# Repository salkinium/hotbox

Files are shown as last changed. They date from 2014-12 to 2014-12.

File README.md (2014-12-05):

# HotBox

HotBox, a solution with the following properties:

1. It allows exposition of sensor motes to a wide range of temper- atures with a high degree of accuracy.
2. It supports specifying exact spatial orientation of motes which, if not ensured, interferes with repeatable experiment setups. 
3. It is reasonably easy to assemble by following the information (code, PCB schematics, hardware list and crafting instructions) available online, facilitating further use of the platforms by other researchers.

For further information have a look at the [HotBox technical report][hotbox].

## Organization

This repository is organized as follows:

- 	The *hardware* folder contains all hardware files for the box.
	-	*hardware/et* contains the PCB schematics and layouts.
	-	*hardware/baseboard* contains the vector files of all parts of the baseboard (for the lasercutter).
	-	*hardware/harness* contains the vector files of all parts of the mote harness (for the lasercutter).
- 	The *software* folder contains the software for the controller.
	- 	*software/source* contains the actual application code for this robot.
	-	*software/xpcc* contains the git submodule for the xpcc.io microcontroller framework.

All hardware and embedded software was designed by [Niklas Hauser][hauser] during his [bachelor thesis][bachelor].

[hotbox]: http://sunsite.informatik.rwth-aachen.de/Publications/AIB/2014/2014-14.pdf
[hauser]: http://www.salkinium.de
[bachelor]: https://github.com/salkinium/bachelor

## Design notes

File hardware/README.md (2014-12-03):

# Box Controller Hardware

## Controller PCB

The controller is build around a ATmega328p on a PCB which contains:

- a UART PSK plug for communication,
- a reset button,
- 4 PSK plugs for I2C bus with pull-ups,
- a ISP programming header,
- 4 mounting holes,
- a ATX 24-pin connector for 3.3V, 5V, PowerOn, 
- a ATX 4-pin connector for 12V,
- 1 external crystal (14.7456 MHz),
- 2 white LEDs, 1 RGB LED all connected to the ATmegas Timer Outputs,
- 1 TMP175 temperature sensor on the I2C bus,
- 4 MOSFETs (BUZ11) with snubber diodes, and
- several 0603 resistors and capacitors.

The PCB is designed to be one-sided so it can be cheaply produced or easily PCB-milled.
However, the ISP reset line has to be connected using wire, since it simply did not fit on one side anymore.

## Mote harness

This is a mote harness for the MTM-CM5000-MSP TelosB mote.
The motes battery pack must be unsolderes, otherwise it won't fit.

The harness rotates the mote around the PCB antenna in 5° steps, so the distance between two rotated motes does not change.
The harness can be clamped onto a distance bar, which allows moving the harness in 5mm steps.

## Box Baseboard

The baseboard is simply a lasercut 5mm thick piece of wood, which holds the controller PCB, the heater, the circulation fan and a disperser using M3 screws.

The heater is a 150W element, and the fan a standard 12V PC fan.

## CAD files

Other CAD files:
hardware/baseboard/Baseboard_5mm.dwg
hardware/harness/length_connector_5mm.dwg
hardware/baseboard/Fan_holder_6mm.dwg
hardware/harness/rotate_wheel_4mm.dwg
hardware/baseboard/wind_director_5mm.dwg
hardware/harness/rotate_all.dwg
hardware/baseboard/Heater_holder_5mm.dwg
hardware/harness/mote_holder_5mm.dwg
hardware/harness/length_bearing_bottom_3mm.dwg
hardware/harness/rotate_bearing_3mm.dwg
hardware/harness/length_measure_5mm.dwg
hardware/harness/rotate_bearing_5mm.dwg
hardware/harness/length_bearing_6mm.dwg
hardware/harness/rotate_base_3mm.dwg

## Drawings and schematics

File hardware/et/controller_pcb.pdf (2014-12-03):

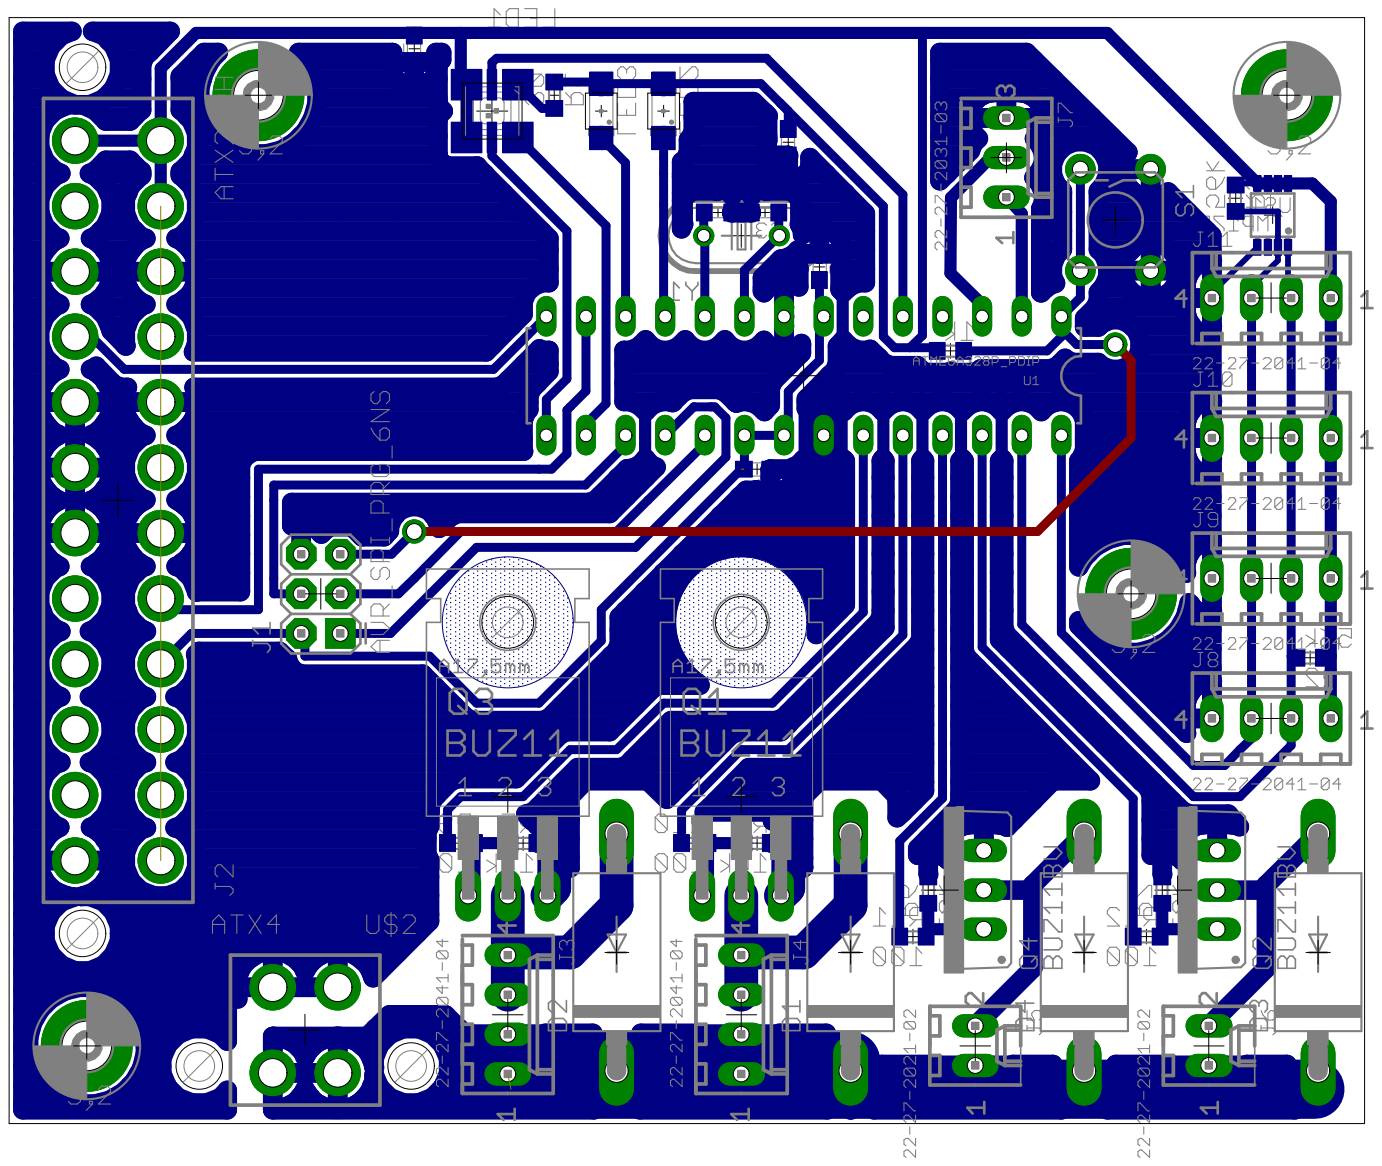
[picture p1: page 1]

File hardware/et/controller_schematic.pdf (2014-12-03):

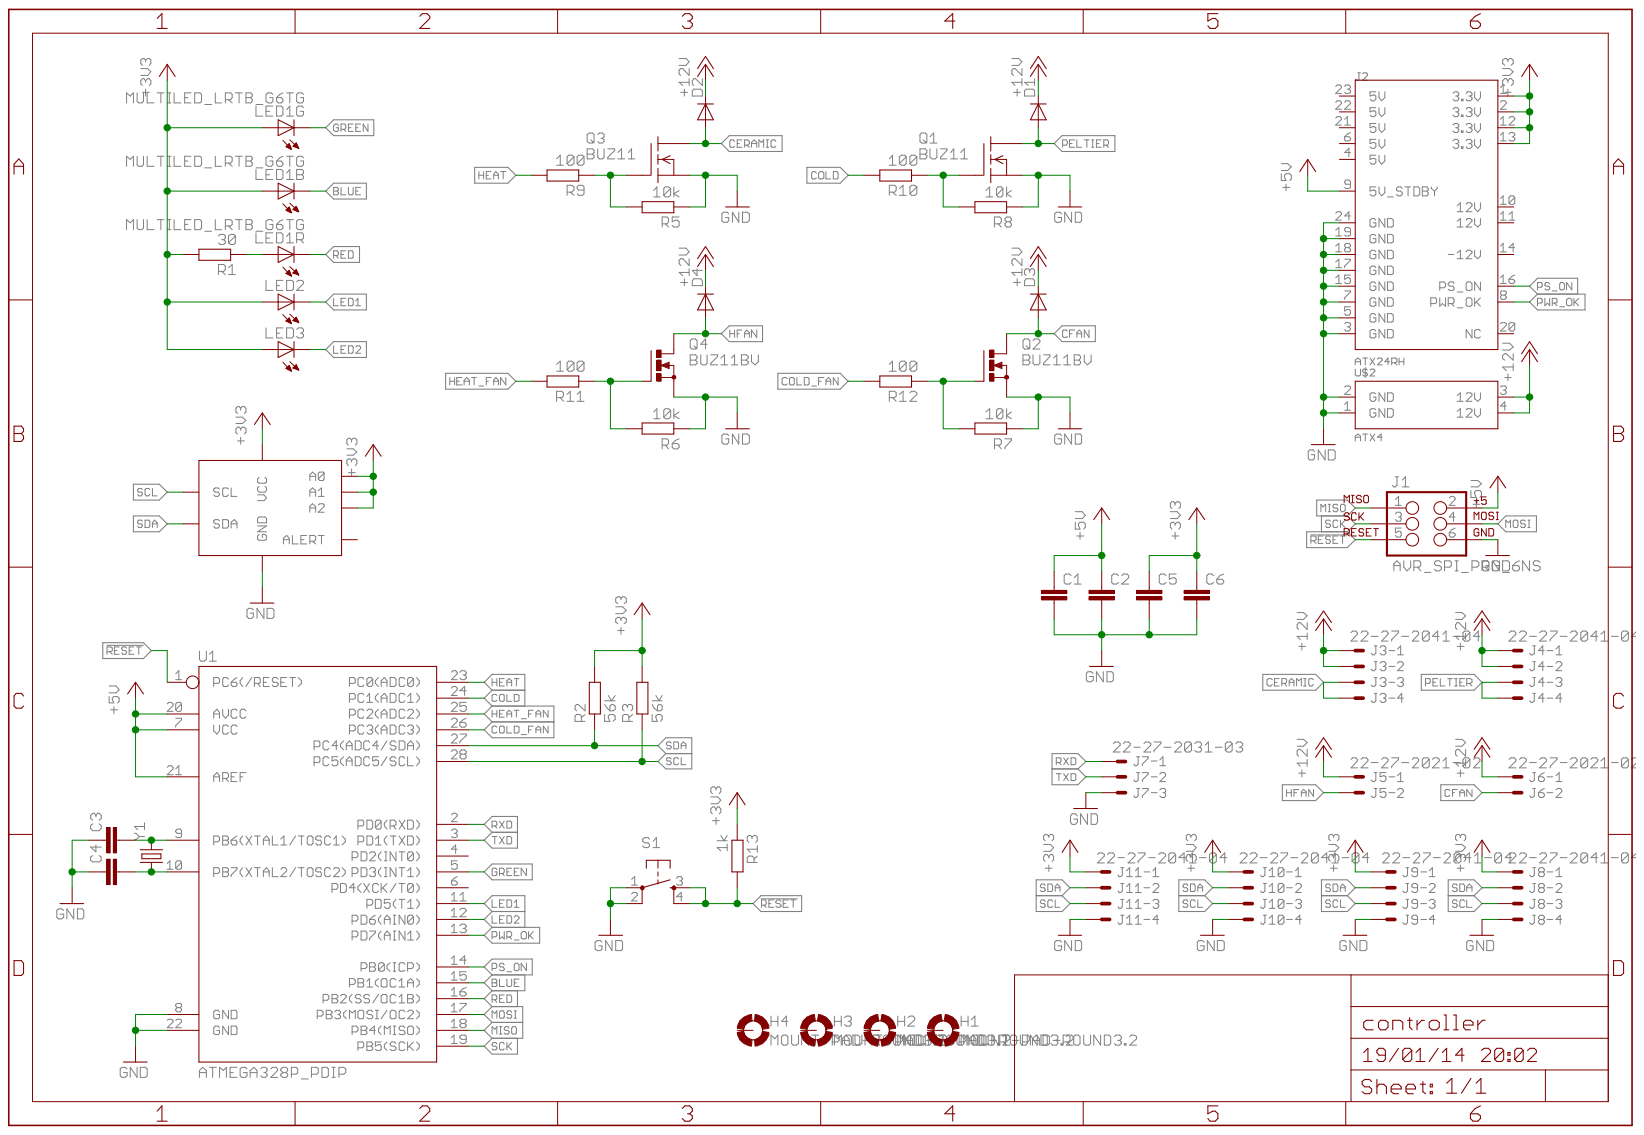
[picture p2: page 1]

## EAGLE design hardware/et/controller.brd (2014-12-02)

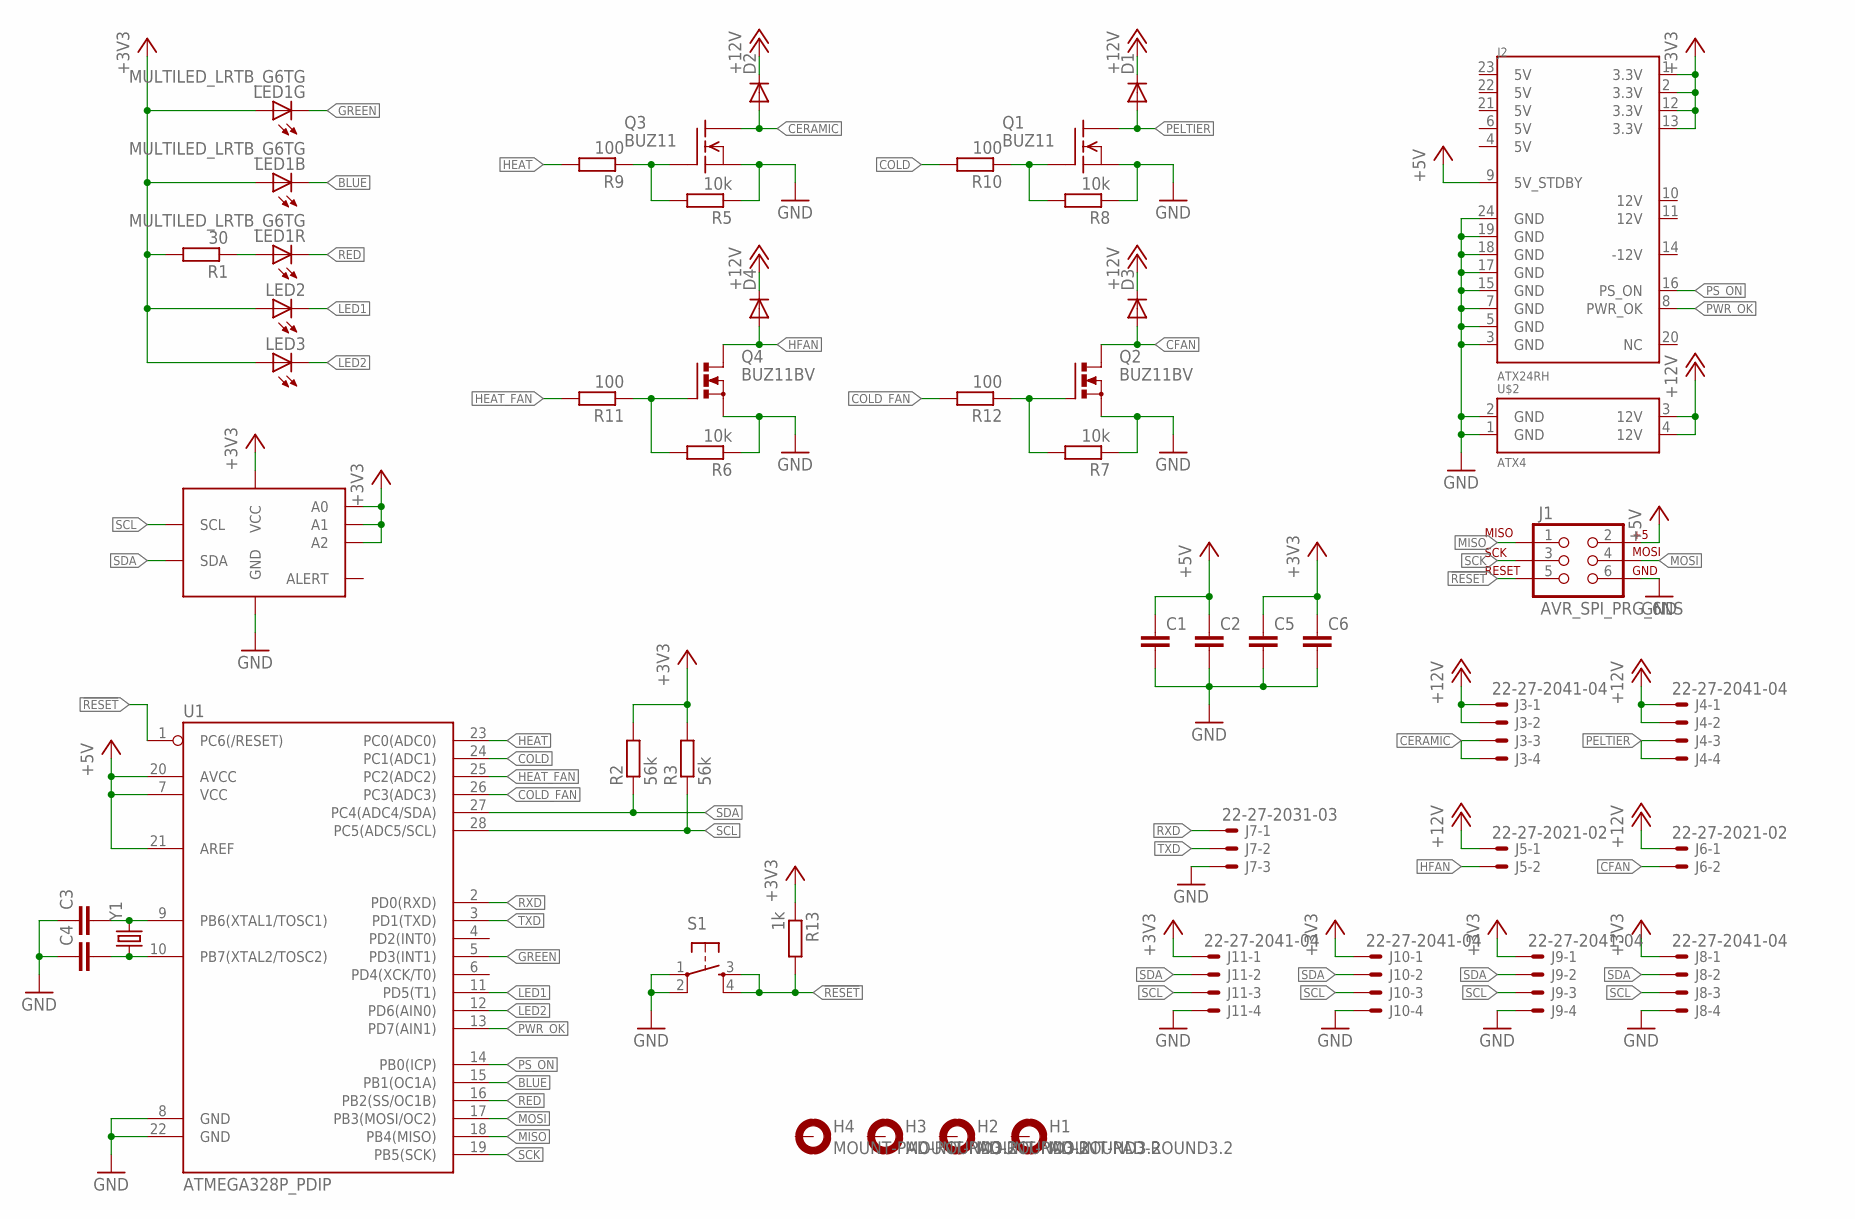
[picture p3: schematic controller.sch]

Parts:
C1, C2, C5, C6: C-EUC0603; C0603
C3, C4: C-EUC0603K; C0603K
D1, D2, D3, D4: DIODE-DO201-15; DO201-15
H1, H2, H3, H4: MOUNT-PAD-ROUND3.2; 3,2-PAD
J1: AVR_SPI_PRG_6NS; 2X3-NS
J2: ATX24RH; ATX24_RIGHT_ANGLE
J3, J4, J8, J9, J10, J11: 22-27-2041-04; 6410-04
J5, J6: 22-27-2021-02; 6410-02
J7: 22-27-2031-03; 6410-03
LED1: MULTILED_LRTB_G6TG; P-LCC-6_TOPLED
LED2, LED3: LEDSML1206; SML1206
Q1, Q3: BUZ11; TO220
Q2, Q4: BUZ11BV; TO220BV
R1: 30; R0603
R2, R3: 56k; R0603
R5, R6, R7, R8: 10k; R0603
R9, R10, R11, R12: 100; R0603
R13: 1k; R0603
S1: TAC_SWITCHPTH; TACTILE-PTH
U1: ATMEGA328P_PDIP; DIL28-3
U$1: TMP175; MSOP8
U$2: ATX4
Y1: CRYSTALHC49UV; HC49U-V

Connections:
!RESET: J1.5, R13.2, S1.3, S1.4, U1.1 (PC6(/RESET))
+3V3: C5.1, C6.1, J2.1 (3.3V), J2.2 (3.3V), J2.12 (3.3V), J2.13 (3.3V), J8.1, J9.1, J10.1, J11.1, LED1.A2 (A), LED1.A3 (A), LED2.A, LED3.A, R1.2, R2.2, R3.2, R13.1, U$1.5 (A2), U$1.6 (A1), U$1.7 (A0), U$1.8 (VCC)
+5V: C1.1, C2.1, J1.2, J2.9 (5V_STDBY), U1.7 (VCC), U1.20 (AVCC), U1.21 (AREF)
+12V: D1.C, D2.C, D3.C, D4.C, J3.1, J3.2, J4.1, J4.2, J5.1, J6.1, U$2.3 (12V), U$2.4 (12V)
BLUE: LED1.C3 (C), U1.15 (PB1(OC1A))
CERAMIC: D2.A, J3.3, J3.4, Q3.2 (D)
CFAN: D3.A, J6.2, Q2.D
COLD: R10.2, U1.24 (PC1(ADC1))
COLD_FAN: R12.2, U1.26 (PC3(ADC3))
GND: C1.2, C2.2, C3.1, C4.1, C5.2, C6.2, J1.6, J2.3 (GND), J2.5 (GND), J2.7 (GND), J2.15 (GND), J2.17 (GND), J2.18 (GND), J2.19 (GND), J2.24 (GND), J7.3, J8.4, J9.4, J10.4, J11.4, Q1.3 (S), Q2.S, Q3.3 (S), Q4.S, R5.1, R6.1, R7.1, R8.1, S1.1, S1.2, U1.8 (GND), U1.22 (GND), U$1.4 (GND), U$2.1 (GND), U$2.2 (GND)
GREEN: LED1.C2 (C), U1.5 (PD3(INT1))
HEAT: R9.2, U1.23 (PC0(ADC0))
HEAT_FAN: R11.2, U1.25 (PC2(ADC2))
HFAN: D4.A, J5.2, Q4.D
LED1: LED2.C, U1.11 (PD5(T1))
LED2: LED3.C, U1.12 (PD6(AIN0))
MISO: J1.1, U1.18 (PB4(MISO))
MOSI: J1.4, U1.17 (PB3(MOSI/OC2))
unnamed: C3.2, U1.9 (PB6(XTAL1/TOSC1)), Y1.2
unnamed: C4.2, U1.10 (PB7(XTAL2/TOSC2)), Y1.1
unnamed: LED1.A1 (A), R1.1
unnamed: Q2.G, R7.2, R12.1
unnamed: Q4.G, R6.2, R11.1
unnamed: Q1.1 (G), R8.2, R10.1
unnamed: Q3.1 (G), R5.2, R9.1
PELTIER: D1.A, J4.3, J4.4, Q1.2 (D)
PS_ON: J2.16 (PS_ON), U1.14 (PB0(ICP))
PWR_OK: J2.8 (PWR_OK), U1.13 (PD7(AIN1))
RED: LED1.C1 (C), U1.16 (PB2(SS/OC1B))
RXD: J7.1, U1.2 (PD0(RXD))
SCK: J1.3, U1.19 (PB5(SCK))
SCL: J8.3, J9.3, J10.3, J11.3, R3.1, U1.28 (PC5(ADC5/SCL)), U$1.2 (SCL)
SDA: J8.2, J9.2, J10.2, J11.2, R2.1, U1.27 (PC4(ADC4/SDA)), U$1.1 (SDA)
TXD: J7.2, U1.3 (PD1(TXD))

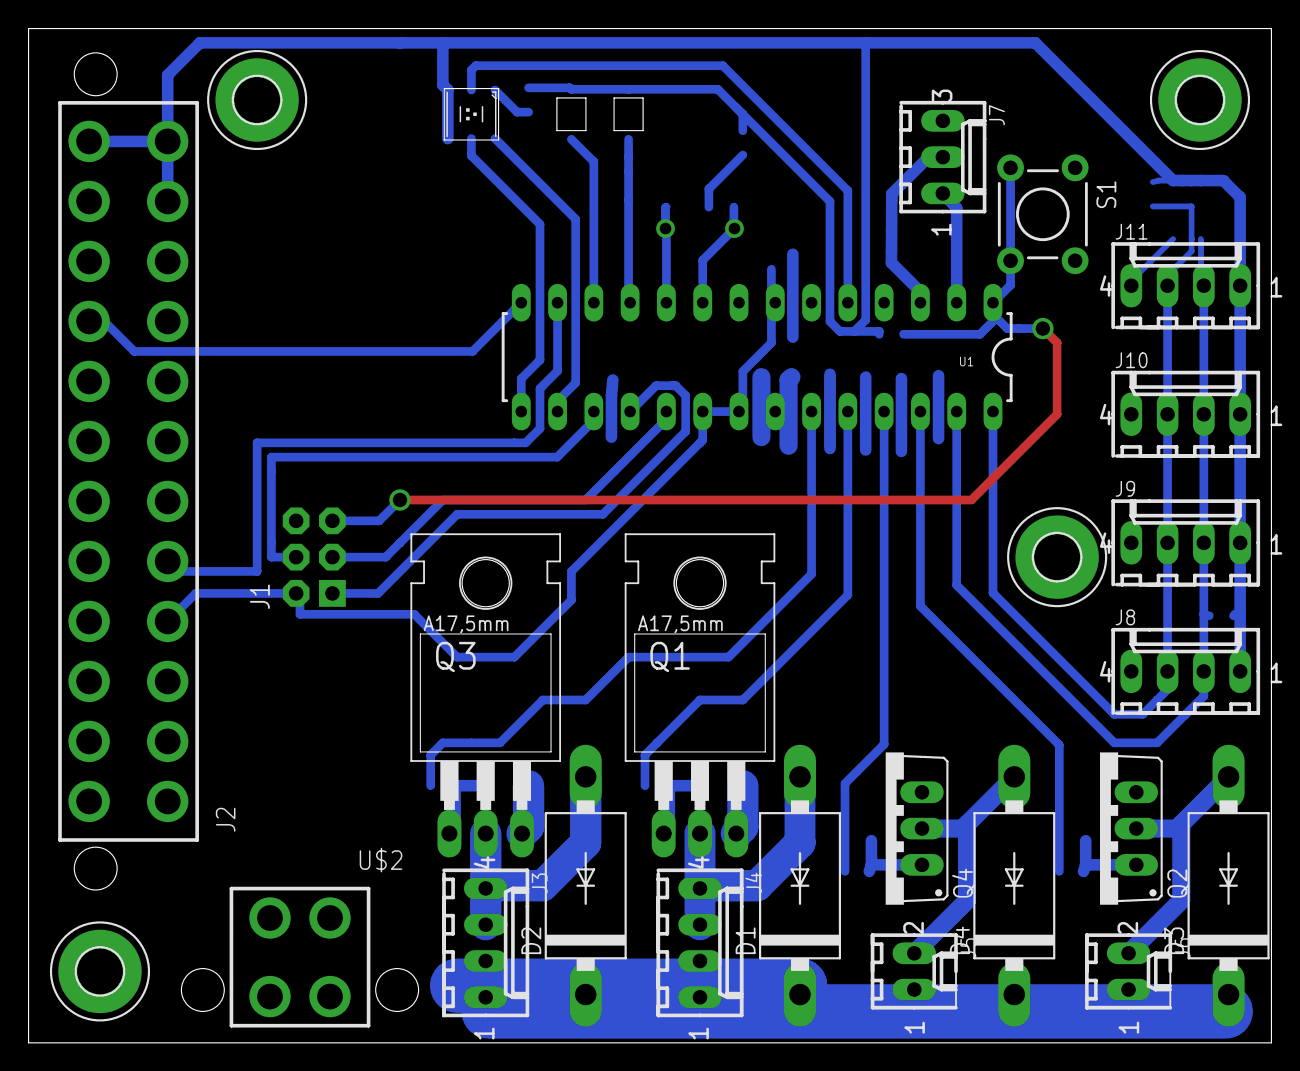
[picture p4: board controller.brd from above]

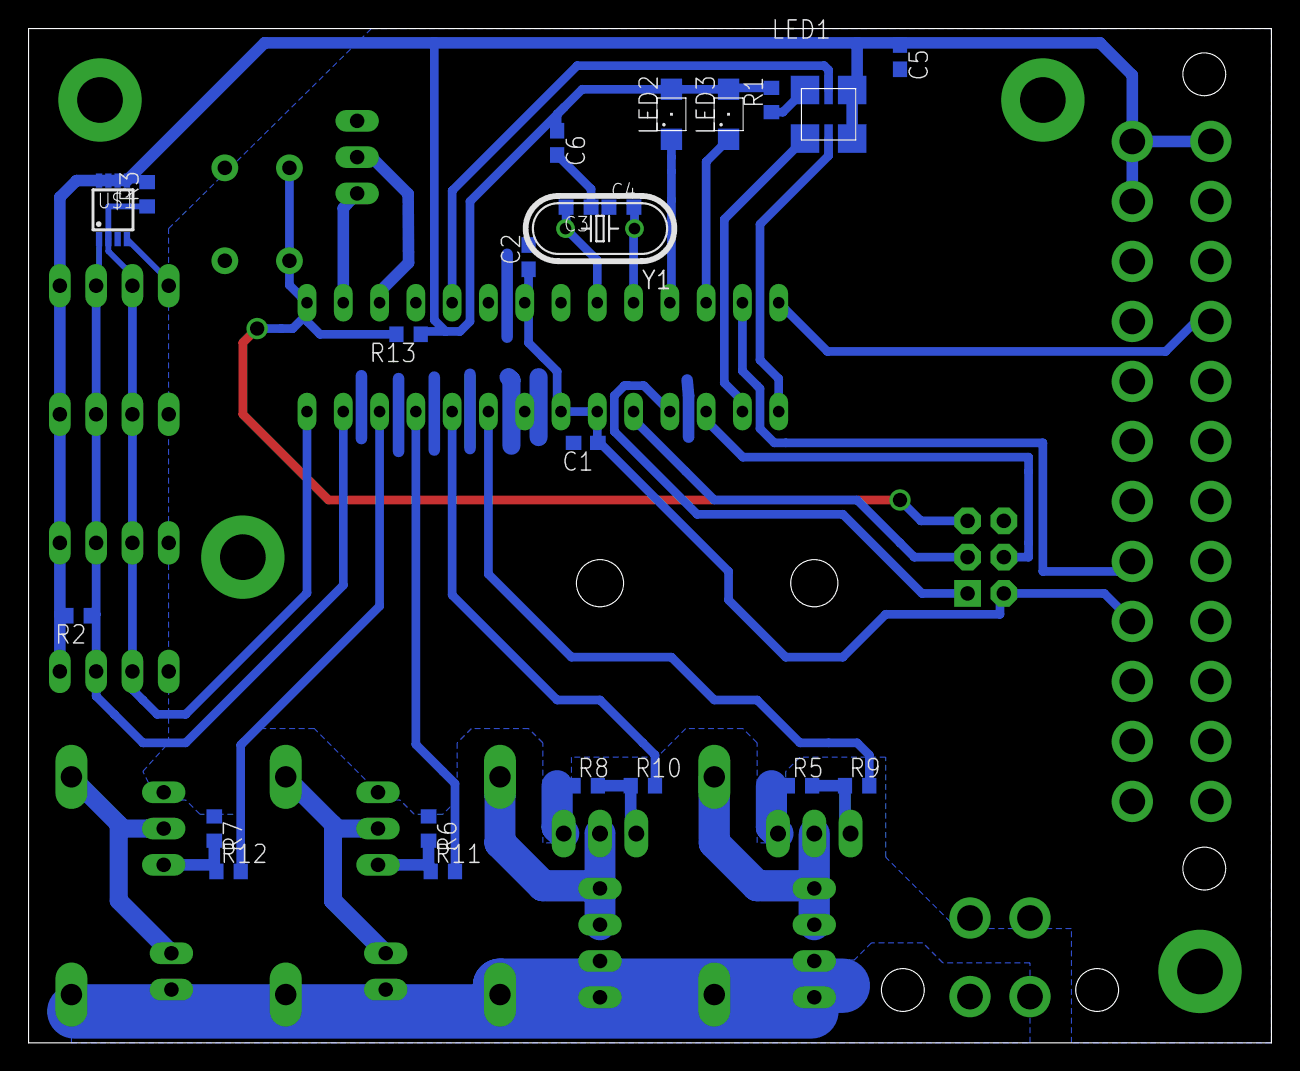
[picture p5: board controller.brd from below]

Board: 2 copper layers, 87.0 x 71.0 mm, 49 parts (23 on the bottom side), 34 nets.

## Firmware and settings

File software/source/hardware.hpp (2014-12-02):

// coding: utf-8
/* Copyright (c) 2013, Niklas Hauser
* All Rights Reserved.
*
* The file is part of the my thesis and is released under the 3-clause BSD
* license. See the file `LICENSE` for the full license governing this code.
*/
// ----------------------------------------------------------------------------

#ifndef THESIS_HARDWARE
#define THESIS_HARDWARE

#include <xpcc/architecture/platform.hpp>

using namespace xpcc::atmega;

// IO #########################################################################
// ATMEL ATMEGA328P
//                    +-v-+
//     (!RESET) PC6  1|   |28  PC5 (SCL)
//        (RXD) PD0  2|   |27  PC4 (SDA)
//        (TXD) PD1  3|   |26  PC3 (HEAT_FAN)
//              PD2  4|   |25  PC2 (COLD_FAN)
// (GREEN,OC2B) PD3  5|   |24  PC1 (HEAT)
//              PD4  6|   |23  PC0 (COLD)
//              VCC  7|   |22  GND
//              GND  8|   |21  AREF
//      (XTAL1) PB6  9|   |20  AVCC
//      (XTAL2) PB7 10|   |19  PB5 (SCK)
//  (LED2,OC0B) PD5 11|   |18  PB4 (MISO)
//  (LED1,OC0A) PD6 12|   |17  PB3 (MOSI)
//     (PWR_OK) PD7 13|   |16  PB2 (RED,OC1B)
//      (PS_ON) PB0 14|   |15  PB1 (BLUE,OC1A)
//                    +---+

// Color
typedef GpioOutputB2 RedLedPin;
typedef GpioOutputD3 GreenLedPin;
typedef GpioOutputB1 BlueLedPin;

// Signal
typedef GpioOutputD6 WhiteLeftLedPin;
typedef GpioOutputD5 WhiteRightLedPin;

// Power
//typedef GpioOpenDrain<GpioB0> PsOn;
typedef GpioOutputB0 PsOn;
typedef GpioInputD7 PwrOk;

// Control
typedef GpioOutputC1 HeaterPin;
typedef GpioOutputC3 HeaterFanPin;
typedef GpioOutputC0 CoolerPin;
typedef GpioOutputC2 CoolerFanPin;

// Leds
#include "leds.hpp"
WhiteLedLeft whiteLedLeft;
WhiteLedRight whiteLedRight;
RedLed redLed;
GreenLed greenLed;
BlueLed blueLed;

xpcc::ui::RgbLed rgbLed(redLed, greenLed, blueLed);

// COMMUNICATION ##############################################################
// Message
struct
{
	uint8_t temperature0[2];
	uint8_t temperature1[2];
	uint8_t temperature2[2];
    uint8_t temperature3[2];
    uint8_t temperature4[2];
} rawSensorData;

// TMP102 and TMP175 drivers
#include <xpcc/driver/temperature/tmp102.hpp>
#include <xpcc/driver/temperature/tmp175.hpp>
/*
typedef GpioC4 Sda;
typedef GpioC5 Scl;
typedef I2cMaster Twi;
/*/
typedef GpioOpenDrain<GpioC4> Sda;
typedef GpioOpenDrain<GpioC5> Scl;
typedef xpcc::SoftwareI2cMaster<Scl, Sda> Twi;
//*/

// This sensor is always present
xpcc::Tmp175<Twi> sensor0(rawSensorData.temperature0, 0b1001111);

// these sensors are purely optional
xpcc::Tmp102<Twi> sensor1(rawSensorData.temperature1, 0b1001000);
xpcc::Tmp102<Twi> sensor2(rawSensorData.temperature2, 0b1001001);
xpcc::Tmp102<Twi> sensor3(rawSensorData.temperature3, 0b1001010);
xpcc::Tmp102<Twi> sensor4(rawSensorData.temperature4, 0b1001011);

// Serial debug
#include <xpcc/io/iodevice_wrapper.hpp>
typedef Uart0 Uart;
xpcc::IODeviceWrapper<Uart> outputDevice;

#include <xpcc/debug/logger/style_wrapper.hpp>
#include <xpcc/debug/logger/style/prefix.hpp>
#include <xpcc/debug/logger.hpp>
xpcc::log::StyleWrapper< xpcc::log::Prefix< char[10] > > loggerDeviceDebug (
		xpcc::log::Prefix< char[10] > ("Debug:   ", outputDevice ) );
xpcc::log::Logger xpcc::log::debug( loggerDeviceDebug );

xpcc::log::StyleWrapper< xpcc::log::Prefix< char[10] > > loggerDeviceInfo (
		xpcc::log::Prefix< char[10] > ("Info:    ", outputDevice ) );
xpcc::log::Logger xpcc::log::info( loggerDeviceInfo );

xpcc::log::StyleWrapper< xpcc::log::Prefix< char[10] > > loggerDeviceWarning (
		xpcc::log::Prefix< char[10] > ("Warning: ", outputDevice ) );
xpcc::log::Logger xpcc::log::warning( loggerDeviceWarning );

xpcc::log::StyleWrapper< xpcc::log::Prefix< char[10] > > loggerDeviceError (
		xpcc::log::Prefix< char[10] > ("Error    ", outputDevice ) );
xpcc::log::Logger xpcc::log::error( loggerDeviceError );

#undef	XPCC_LOG_LEVEL
#define	XPCC_LOG_LEVEL xpcc::log::DEBUG


// TASKS ######################################################################
#include "tasks/task_software_pwm.hpp"
task::SoftwarePwm<HeaterPin, 333> heater(whiteLedLeft);
task::SoftwarePwm<HeaterFanPin, 33> heaterFan(whiteLedRight);

#include "tasks/task_temperature.hpp"
task::Temperature temperature;

#include "tasks/task_temperature_control.hpp"
task::TemperatureControl temperatureControl;

#include "tasks/task_io.hpp"
task::IO inputOutput(temperature, temperatureControl);

#endif // THESIS_HARDWARE

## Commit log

2014-12-02 Add hardware files.
    [Baseboard.dwg, Baseboard.dxf, Distance_rings.dwg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]
2014-12-02 Add software files.
    [project.cfg]
2014-12-03 Add READMEs and harness files.
    [Baseboard.dwg, Baseboard.dxf, Baseboard_5mm.dwg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]

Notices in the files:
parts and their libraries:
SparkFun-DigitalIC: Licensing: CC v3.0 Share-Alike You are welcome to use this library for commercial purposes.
